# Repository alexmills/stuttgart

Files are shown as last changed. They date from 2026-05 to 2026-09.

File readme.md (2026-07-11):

# Project Stuttgart

*Last Updated: 11th July 2026*

> Named after the founding location of Bosch in 1886, where a team in 1983 started development of the Connected Area Network.

The goal for this research project is to explore the benefits of having a clearer look at the CAN bus during vehicle diagnostics, instead of relying solely on multimeter or oscilloscope measurements.

## Overview

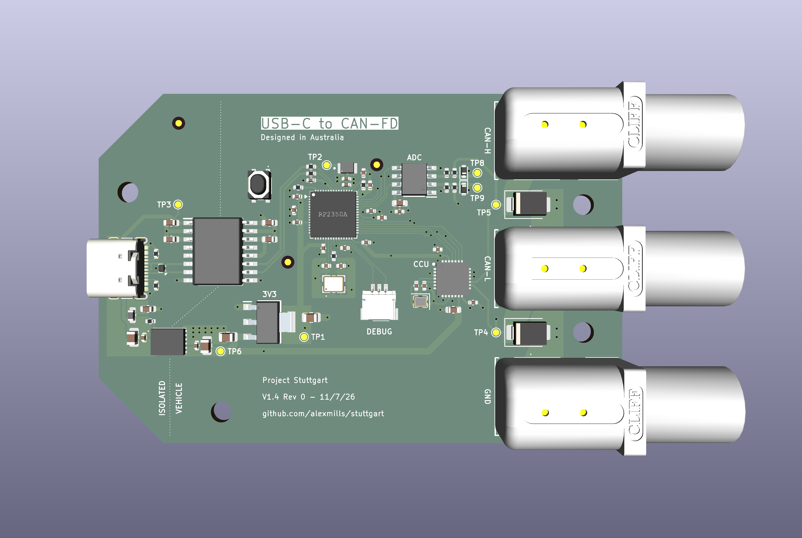
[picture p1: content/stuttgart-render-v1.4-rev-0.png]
Rev-0 3D Render


The tool connects to the CAN bus in a **read only** capacity, receiving messages and monitoring bus health while simultaneously measuring the voltage on the High and Low signal lines to identify physical layer faults. The CAN controller's transmit line is still connected for some future experiments with J1939.

A small web app connects to the tool using WebSerial (in Chrome/Edge) to control and monitor its data output in real time. 

*The design and component selection **will not** take production into consideration, this is purely a research project. I get easily sidetracked worrying about how to make n-amount instead of just making one first...*
## Isolation & Safety

The microcontroller and USB are completely isolated from the components connected to the vehicle electronics through the CAN bus, protecting the laptop and user from any potential voltage differences between chassis ground and mains earth. This isolation also eliminates ground loops, improves signal integrity, and provides a clean ground reference for the vehicle measurements.

## Target Vehicle / Networks

Primary targets are heavy duty vehicles which use a combination of J1939 and J2284 networks. The initial goal of the tool is not to decode these messages but to verify the bus is healthy and that frames are being transmitted without errors or corruption.

Both standards build on ISO 11898 *Road Vehicles - Controller Area Network (CAN),* with their own additions and modifications.

**J1939** spans both **physical** and **application** layers, defining its own physical layer specifications as well as how the messages are structured and what they mean. Unlike J2284, the use of CAN 2.0B 29-bit extended identifiers is mandated.

**J2284** defines the **physical** layer and portions of the **data link** layer, with OBD-II, UDS and proprietary **application** layers running on top. Both standards reference ISO 11898-2 for the high speed CAN physical layer, meaning the bus voltage levels are identical and the same transceiver hardware can be used across all target networks.

## Status

The current state of the project as follows:

- [x] Project Scope
- [x] Architecture & Protocol Design
- [x] Component Selection
- [x] Schematic Design
- [x] PCB Design
- [ ] Enclosure Design (Active)
- [ ] Firmware Implementation (Active)
- [ ] App Implementation (Active)
- [ ] Testing

## Updates 

### 11th July 2026
Order with JLC has been placed! Got stung with extended library part swaps so will need to revise that in the future because it was quite expensive.

## Main Components

| Component | Part No | JLC No | Status | Models |
| --- | --- | --- | --- | --- |
| MCU | Raspberry Pi RP2354A | C41378174 | ✅ | 📦 |
| CAN FD Controller | Microchip MCP251863 | C20295647 | ✅ | ✅ |
| Voltage ADC | MCP3202-CI/SN | C56997 | ✅ | ✅ |
| Isolated DC-DC | TI UCC33420 | C46461551 | ✅ | ✅ |
| Isolated USB | TI ISOUSB111DWR | C5216549  | ✅ | ✅ |
| 3.3V LDO | OnSemi NCV1117ST33T3G | C114733 | ✅ | ✅ |
| MCP2518FD Crystal | Murata XRCGE20M000F3A1AR0 | C6758395  | ✅ | 📦 |
| 12MHz Crystal | Abracon ABM8-272-T3 | C20625731 | ✅ | ✅ |
| SMPS Inductor | Abracon AOTA-B201610S3R3-101T | C42411119 | ✅ | ✅ |
| Transceiver TVS Diodes | Littelfuse SMBJ5.0A | C83333 | ✅ | 📦 |
| ADC Zener Diodes | Onsemi SZMM5Z3V3T1G | C464127 | ✅ | 📦 |
| BOOTSEL Button | Wurth 434133025816 | C5504987  | ✅ | ✅ |
| USB-C Connector | GCT USB4105-GF-060 | C3025063  | ✅ | 📦 |
| SWD Header | JST SM03B-SRSS-TB | C160403 | ✅ | ✅ |
| CANH Socket | Cliff FCR7350Y (Blue) | Digikey | ✅ | ✅ |
| CANL Socket | Cliff FCR7350G (Green) | Digikey | ✅ | ✅ |
| GND Socket | Cliff FCR7350B (Black) | Digikey | ✅ | ✅ |

## System Architecture

Below is the high level architecture of the system, including the USB/Vehicle isolation and main active components.

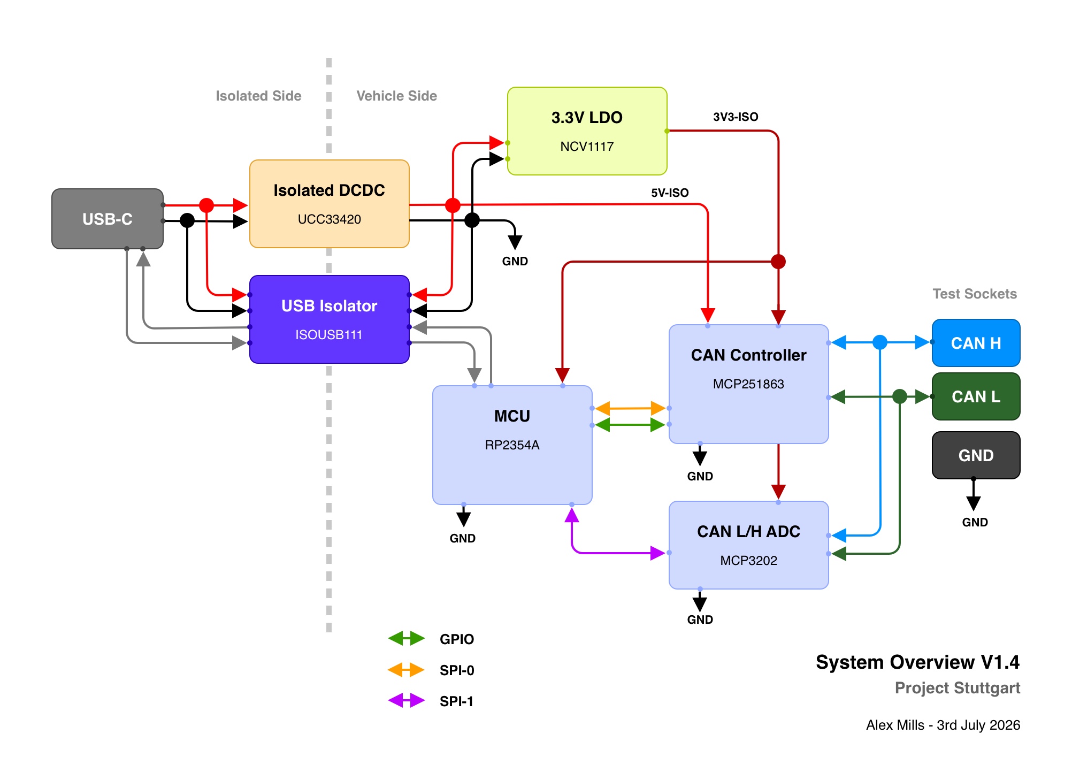
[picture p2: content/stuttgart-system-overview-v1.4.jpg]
System Overview


### Vehicle / USB Isolation

The VBUS from the USB-C connector is isolated using a Texas Instruments UCC33420 DC-DC Converter, providing 1.5W / 300mA to the 5V Rail.

The USB data is isolated using a Texas Instruments ISOUSB111 USB Isolator, which sits between the USB-C Connector and RP2354. Combining this IC with the DC-DC converter means the main components on the PCB sit on the "vehicle side", completely isolated from the USB port and connected computer.

### Vehicle Interface

The CAN communication to the vehicle is achieved using a Microchip MCP251863, integrating the MCP2518-FD Controller and ATA6563 Transceiver into a single package ([Datasheet]([https://ww1.microchip.com/downloads/aemDocuments/documents/OTH/ProductDocuments/DataSheets/External-CAN-FD-Controller-with-SPI-Interface-DS20006027B.pdf](https://ww1.microchip.com/downloads/aemDocuments/documents/APID/ProductDocuments/DataSheets/MCP251863-External-CAN-FD-Controller-with-Integrated-Transceiver-DS200066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))). The CAN Signals and vehicle reference ground are provided through CLIFF 4mm 1kV "banana" sockets usually found on multimeters, so my normal test leads and accessories can be used.

## Power Requirements

### 3V3 Rail

| Component | Typical  | Max | Notes |
| --- | --- | --- | --- |
| RP2354 | 16mA | 20mA | USB Comms Test |
| MCP2518FD | 15mA | 20mA | 40MHz SYSCLK |
| ATA6563 | 0.25mA | 0.5mA | VIO 3V3 Logic Pin |
| MCP3202 | 0.4mA | 0.55mA | VSS = 5.0V |
| **TOTAL** | **32mA** | **41mA** | |

The RP2354 draws around 16mA with constant data being written to the USB port as per the hardware data sheet. 

### LDO Thermal

The recommended LDO for the RP2354 is the NCP1117 family of which we are using the automotive version, NCV1117

**OnSemi NCP1117**
- Output: 1.0A @ 3.3V
- Maximum Junction Temperature Range: -55c to 150c
- Junction-to-ambient thermal resistance: 160c/W (SOT-223 worst case)

At maximum load of 41mA the LDO dissipates 70mW as heat, causing a junction rise above ambient of only 11c. With a realistic max enclosure temperature of 55c, a junction temperature of 66c is well within limits.

### Isolated 5V Rail

| Condition | ATA6563 | ISOUSB111 | 5V Direct Total |
| --- | --- | --- | --- |
| Startup / No Monitor | 0mA (STBY) | ~12-15mA  | **~12-15mA** |
| Passive (recessive)  | ~2-5mA | ~12-15mA  | **~14-20mA** |
| TX Burst (max dom) | 70mA | ~15mA | **~85mA** |
| **CANL/H Short** | **85mA** | **~15mA** | **~100mA** |

### Total 5V DC-DC Load

3V3 rail load reflected through the LDO at ~1:1

| Condition | 3V3 LDO | 5V Direct  | DC-DC Total | Power @ 5V |
| --- | --- | --- | --- | --- |
| Startup / No Monitor  | ~32mA | ~12mA | ~44mA | ~220mW |
| Passive Monitor (max) | ~41mA | ~17mA | ~58mA | ~290mW |
| TX Burst (max dom) | ~41mA | ~85mA | ~126mA | ~630mW |
| **Short Fault (max)** | **~32mA** | **~100mA** | **~141mA**  | **~705mW** |

### DC-DC Converter Thermal

**TI UCC33420**
- 1.5W / 300mA @ 5.0V
- Recommended Junction Temperature Range: -40 to 125c 
- Junction-to-ambient thermal resistance: 59.7c/W
- Dissipation at full load: 1050mW
- Efficiency: ~59%

At the worst case scenario, we draw 141mA or 705mW from the converter which at roughly 59% efficiency requires an input load of 1195mW or 240mA, of which 490mW is dissipated as heat equalling a rise of 29c above ambient. With the realistic max enclosure temperature of 55c, the junction temperature of 84c is well within limits.

For 99% of the time the load is much smaller at around 290mW, requiring 492mW of which 202mW is lost as heat, causing a junction rise above ambient of only 12c. 

### USB Requirements

| Condition | DC-DC Load | ISOUSB111 | VBUS Total |
| --- | --- | --- | --- |
| Startup / No Monitor  | 74mA / 372mW | ~12-15mA  | ~89mA |
| Passive Monitor (max) | 98mA / 492mW | ~12-15mA  | ~113mA |
| TX Burst (max dom) | 213mA / 1068mW | 15mA | ~228mA |
| Short Fault (max) | 240mA / 1195W  | 15mA | ~256mA |

With the transceiver in standby mode until needed, our system power requirements at boot are under the 100mA USB initial limit, which can be upped to 400-500mA with negotiations by the RP2354.

## Bus ADC Measurements

The voltage divider for each bus is `R1 = 10kΩ` and `R2 = 47kΩ` so the ratio is calculated as:

```
Vout = Vin x (R2 / (R1 + R2))
Vout = Vin x (47,000 / (10,000 + 47,000))
Vout = Vin x (47,000 / 57,000)
Vout = Vin x 0.8246
```

Below are the estimated values for the ADC measurements at various bus voltages using the above divider with a protection zener diode, clamping at ~3.3V, keeping the ADC within safe limits (3.6V Max). 

| Bus Voltage | ADC Voltage | RAW ADC Value | Notes |
| --- | --- | --- | --- |
| 0 | 0 | 0 | Bus Dead / Off |
| 1.5 | 1.237 | 1535 | CAN L Dominant |
| 2.5 | 2.062 | 2559 | Recessive Idle |
| 3.5 | 2.886 | 3583 | CAN H Dominant |
| **3.9** | **3.223** | **4000** | **Clean bus fault threshold** |
| 4.0 | 3.300 | 4095 | Zener Activates |
| Over 4.0 | 3.300 | 4095 | Clamped - Fault Condition |

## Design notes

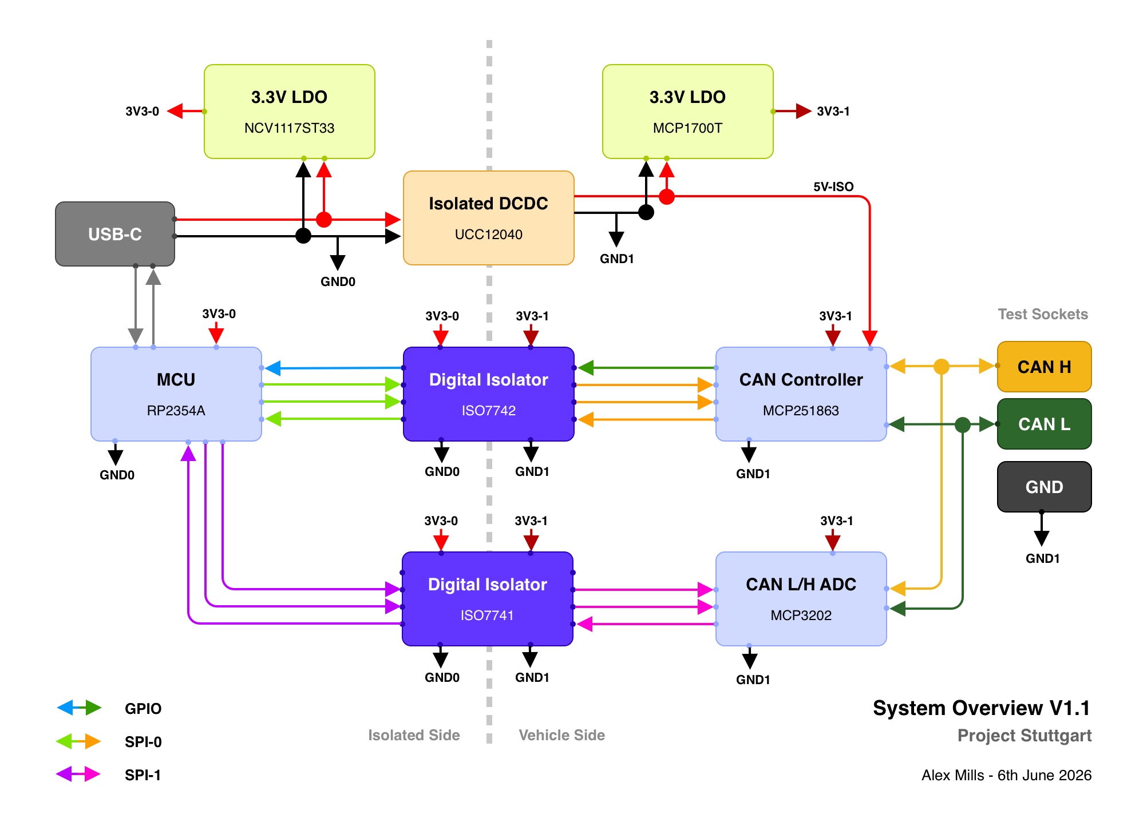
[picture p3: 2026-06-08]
content/stuttgart-system-overview-v1.1.jpg

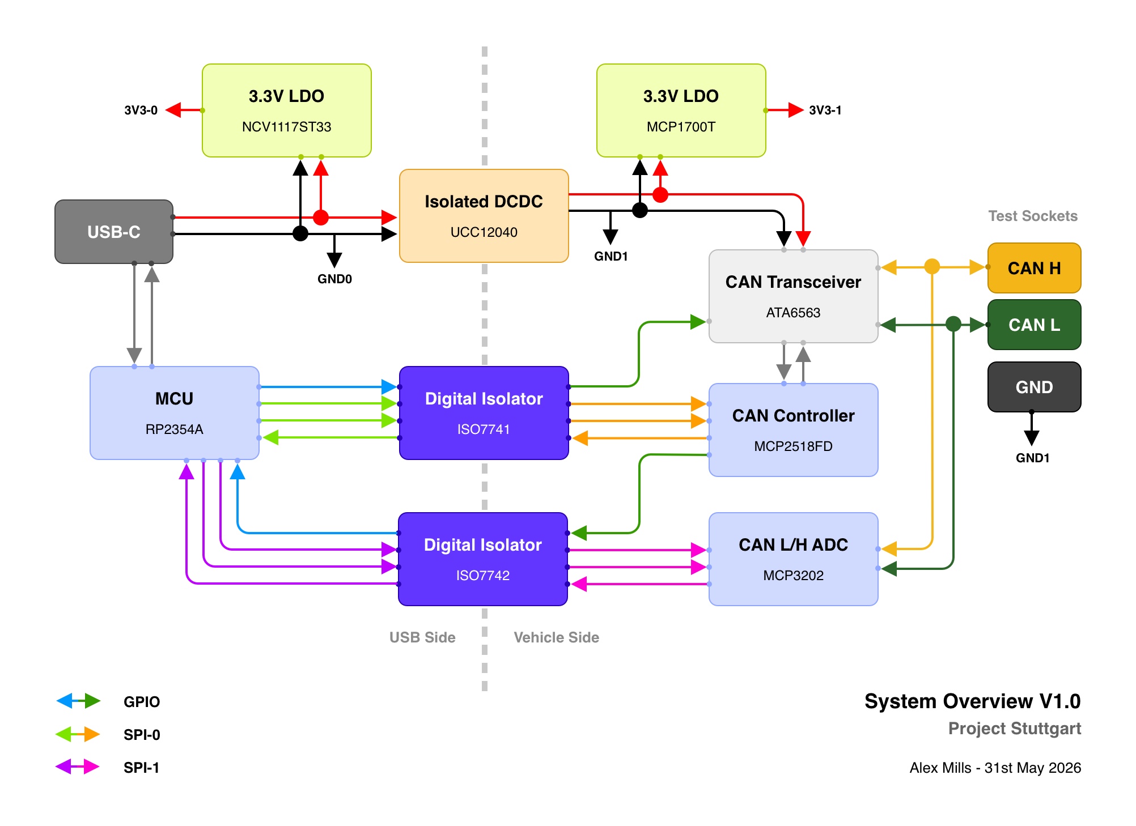
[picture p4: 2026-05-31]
content/stuttgart-system-overview-v1.jpg

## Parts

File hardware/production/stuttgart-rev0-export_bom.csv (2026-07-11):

Designator | Footprint | Quantity | Value | LCSC Part #
C1, C10, C2, C29, C3, C30, C31, C4, C5, C6, C7, C8 | 0402 | 12 | 100n
C11, C12, C18 | 0805 | 3 | 10u
C13, C14 | 0402 | 2 | 15p
C15, C16, C17, C9 | 0402 | 4 | 4.7u
C19, C20 | 0402 | 2 | 15n
C21 | 0805 | 1 | 22u
C28 | 0603 | 1 | 10u
C32, C35 | 0603 | 2 | 100n
C33, C34 | 0402 | 2 | 6p
C36, C37 | 0603 | 2 | 1u
C38, C39 | 0603 | 2 | 0.1u
D1, D2 | D_SOD-523 | 2 | MM5Zxx
D3, D4 | D_SMB | 2 | SM6T6V8A
FB1 | 0603 | 1 | FerriteBead
IC1 | SOT230P700X180-4N | 1 | NCV1117ST33T3G
IC2 | UCC33020QRAQRQ1 | 1 | UCC33420QRAQRQ1
IC3 | SOIC127P1030X265-16N | 1 | ISOUSB111DWR
IC6 | SOIC127P600X175-8N | 1 | MCP3202-CI_SN
IC7 | QFN50P500X500X90-29N-D | 1 | MCP251863T-E_9PX
J1 | USB_C_Receptacle_GCT_USB4105-xx-A_16P_TopMnt_Horizontal | 1 | USB_C_Receptacle_USB2.0_16P
J5 | SM03BSRSSTBLFSN | 1 | SM03B-SRSS-TB_LF__SN_
L1 | AOTAB201610S3R3101T | 1 | AOTA-B201610S3R3-101-T
R1, R2 | 0402 | 2 | 27
R10, R8 | 0402 | 2 | 10k
R11, R9 | 0402 | 2 | 47k
R12 | 0402 | 1 | 18k
R3, R6 | 0402 | 2 | 1k
R4, R5 | 0402 | 2 | 5.1k
R7 | 0402 | 1 | 33
S1 | 434133025816 | 1 | 434133025816
U1 | QFN-60-1EP_7x7mm_P0.4mm_EP3.4x3.4mm | 1 | RP2354A
U2 | Texas_DRT-3 | 1 | TPD2EUSB30
Y1 | ABM8272T3 | 1 | ABM8-272-T3
Y2 | Crystal_SMD_2016-4Pin_2.0x1.6mm | 1 | Crystal_GND24

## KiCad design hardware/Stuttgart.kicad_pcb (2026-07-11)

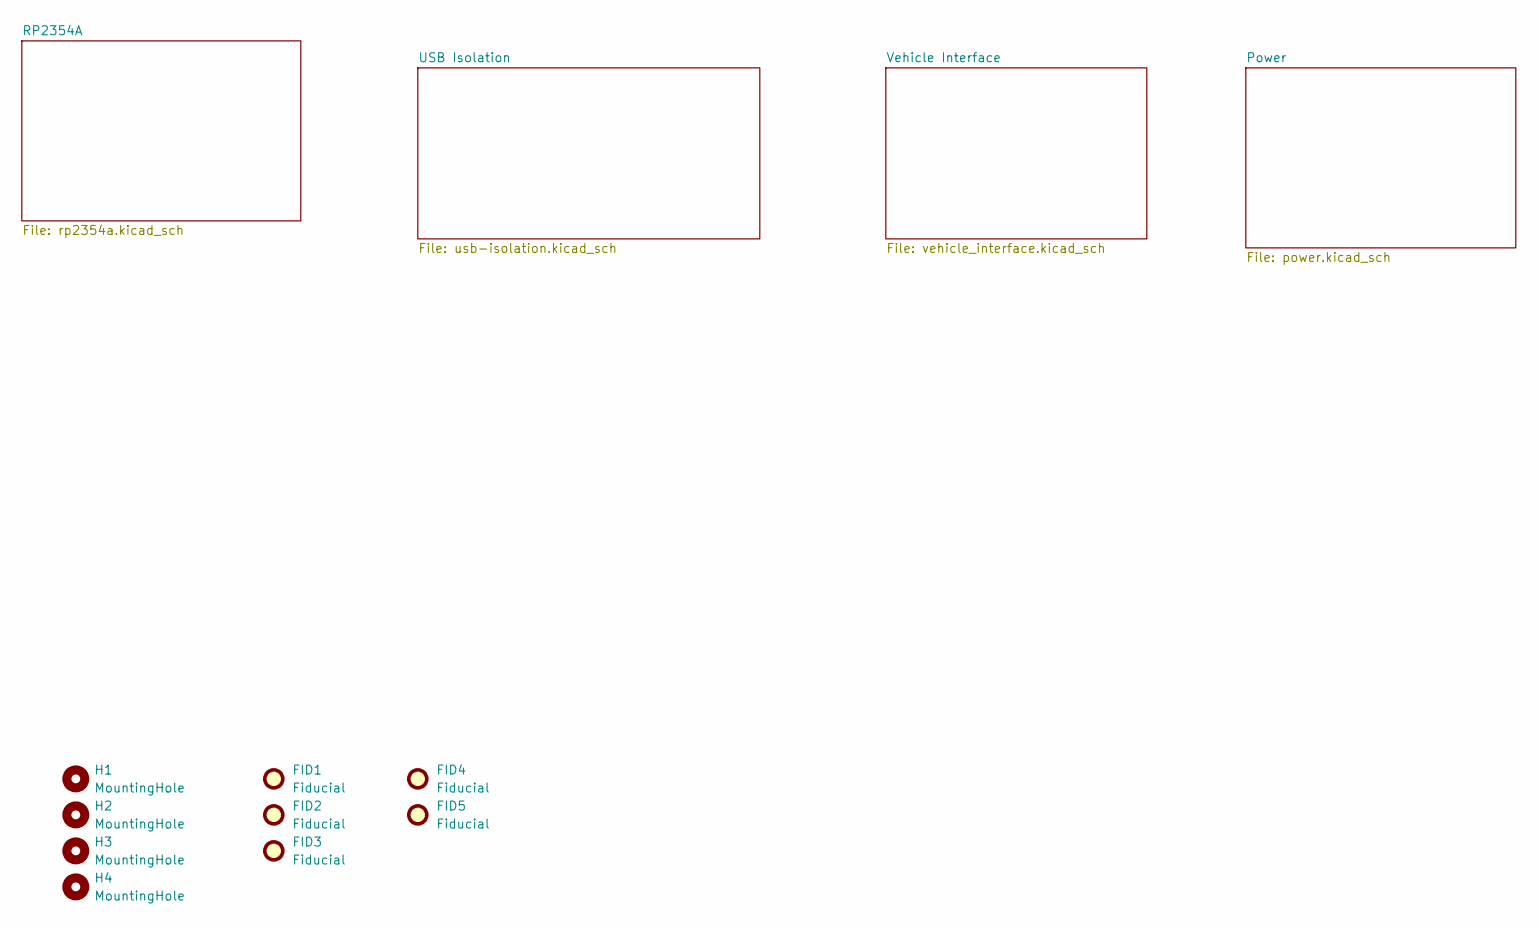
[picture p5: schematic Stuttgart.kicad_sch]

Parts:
FID1, FID2, FID3, FID4, FID5: Fiducial; Fiducial_1mm_Mask2mm
H1, H2, H3, H4: MountingHole; MountingHole_3.2mm_M3

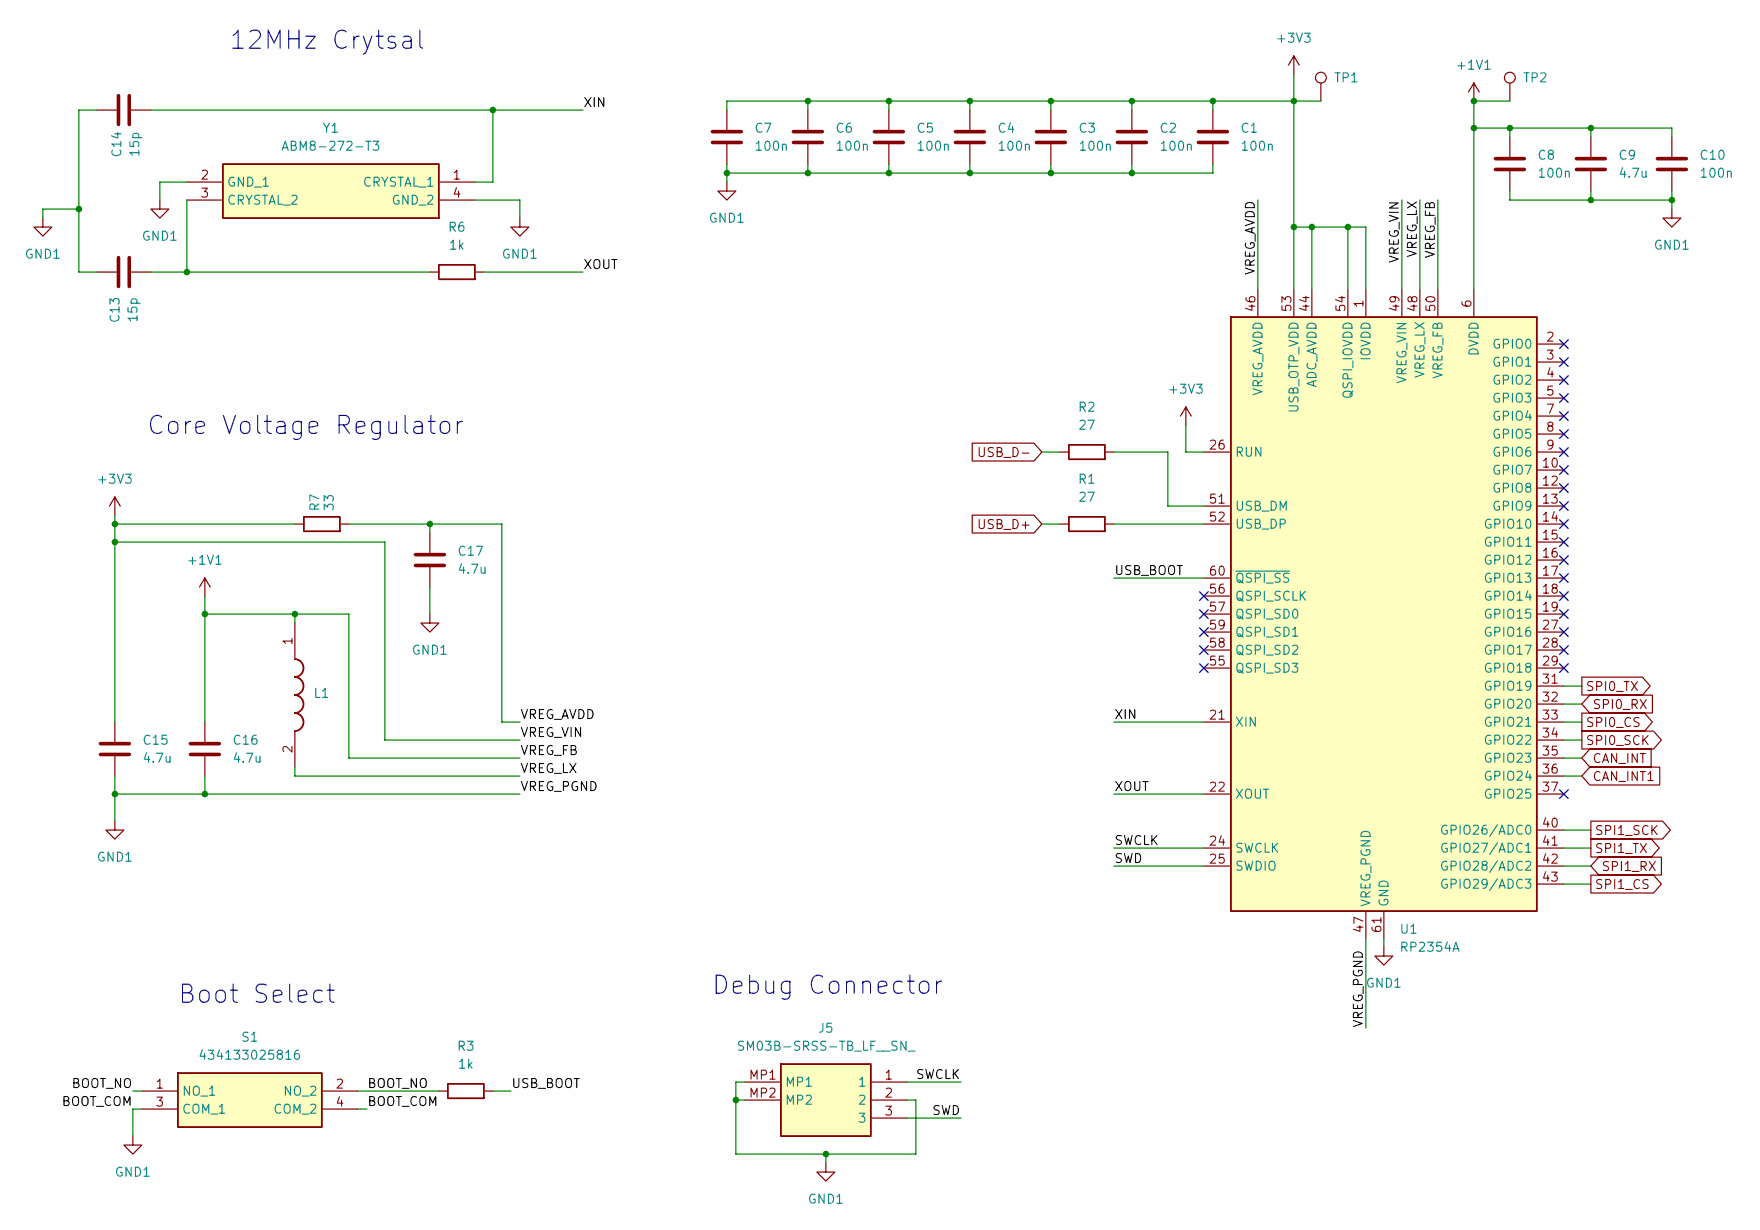
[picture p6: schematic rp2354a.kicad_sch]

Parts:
C1, C2, C3, C4, C5, C6, C7, C8, C10: 100n; C_0402_1005Metric
C9, C17: 4.7u; C_0402_1005Metric
C13, C14: 15p; C_0402_1005Metric
C15, C16: 4.7u; C_0402_1005Metric_small_pads
J5: SM03B-SRSS-TB_LF__SN_; SM03BSRSSTBLFSN; Manufacturer_Part_Number SM03B-SRSS-TB(LF)(SN); JLC Part Number C160403
L1: AOTA-B201610S3R3-101-T; AOTAB201610S3R3101T; Mouser Part Number 815-AB201610S3R3101T
R1, R2: 27; R_0402_1005Metric
R3, R6: 1k; R_0402_1005Metric
R7: 33; R_0402_1005Metric
S1: 434133025816; Manufacturer_Part_Number 434133025816; JLC Part Number C5504987
TP1, TP2: TestPoint; TestPoint_Pad_D1.0mm
U1: RP2354A; QFN-60-1EP_7x7mm_P0.4mm_EP3.4x3.4mm; JLC Part Number C41378174
Y1: ABM8-272-T3; ABM8272T3; Mouser Part Number 815-ABM8-272-T3

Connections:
+1V1: C8.1, C9.1, C10.1, C16.1, L1.1, TP2.1 (1_1), U1.6 (DVDD), U1.23 (DVDD), U1.39 (DVDD), U1.50 (VREG_FB)
+3V3: C1.1, C2.1, C3.1, C4.1, C5.1, C6.1, C7.1, C15.1, R7.1, TP1.1 (1_1), U1.1 (IOVDD), U1.11 (IOVDD), U1.20 (IOVDD), U1.26 (RUN), U1.30 (IOVDD), U1.38 (IOVDD), U1.44 (ADC_AVDD), U1.45 (IOVDD), U1.49 (VREG_VIN), U1.53 (USB_OTP_VDD), U1.54 (QSPI_IOVDD); also elsewhere on the board
/RP2354A/BOOT_NO: R3.1, S1.1 (NO_1), S1.2 (NO_2)
/RP2354A/SWCLK: J5.1, U1.24 (SWCLK)
/RP2354A/SWD: J5.3, U1.25 (SWDIO)
/RP2354A/USB_BOOT: R3.2, U1.60 (~QSPI_SS)
/RP2354A/VREG_AVDD: C17.1, R7.2, U1.46 (VREG_AVDD)
/RP2354A/VREG_LX: L1.2, U1.48 (VREG_LX)
/RP2354A/XIN: C14.2, U1.21 (XIN), Y1.1 (CRYSTAL_1)
/RP2354A/XOUT: R6.2, U1.22 (XOUT)
CAN_INT: U1.35 (GPIO23); also elsewhere on the board
CAN_INT1: U1.36 (GPIO24); also elsewhere on the board
GND1: C1.2, C2.2, C3.2, C4.2, C5.2, C6.2, C7.2, C8.2, C9.2, C10.2, C13.2, C14.1, C15.2, C16.2, C17.2, J5.2, J5.MP1, J5.MP2, S1.3 (COM_1), S1.4 (COM_2), U1.47 (VREG_PGND), U1.61 (GND), Y1.2 (GND_1), Y1.4 (GND_2); also elsewhere on the board
unnamed: R2.2, U1.51 (USB_DM)
unnamed: R1.2, U1.52 (USB_DP)
unnamed: C13.1, R6.1, Y1.3 (CRYSTAL_2)
SPI0_CS: U1.33 (GPIO21); also elsewhere on the board
SPI0_RX: U1.32 (GPIO20); also elsewhere on the board
SPI0_SCK: U1.34 (GPIO22); also elsewhere on the board
SPI0_TX: U1.31 (GPIO19); also elsewhere on the board
SPI1_CS: U1.43 (GPIO29/ADC3); also elsewhere on the board
SPI1_RX: U1.42 (GPIO28/ADC2); also elsewhere on the board
SPI1_SCK: U1.40 (GPIO26/ADC0); also elsewhere on the board
SPI1_TX: U1.41 (GPIO27/ADC1); also elsewhere on the board
USB_D+: R1.1; also elsewhere on the board
USB_D-: R2.1; also elsewhere on the board

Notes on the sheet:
Debug Connector
Boot Select
12MHz Crytsal
Core Voltage Regulator

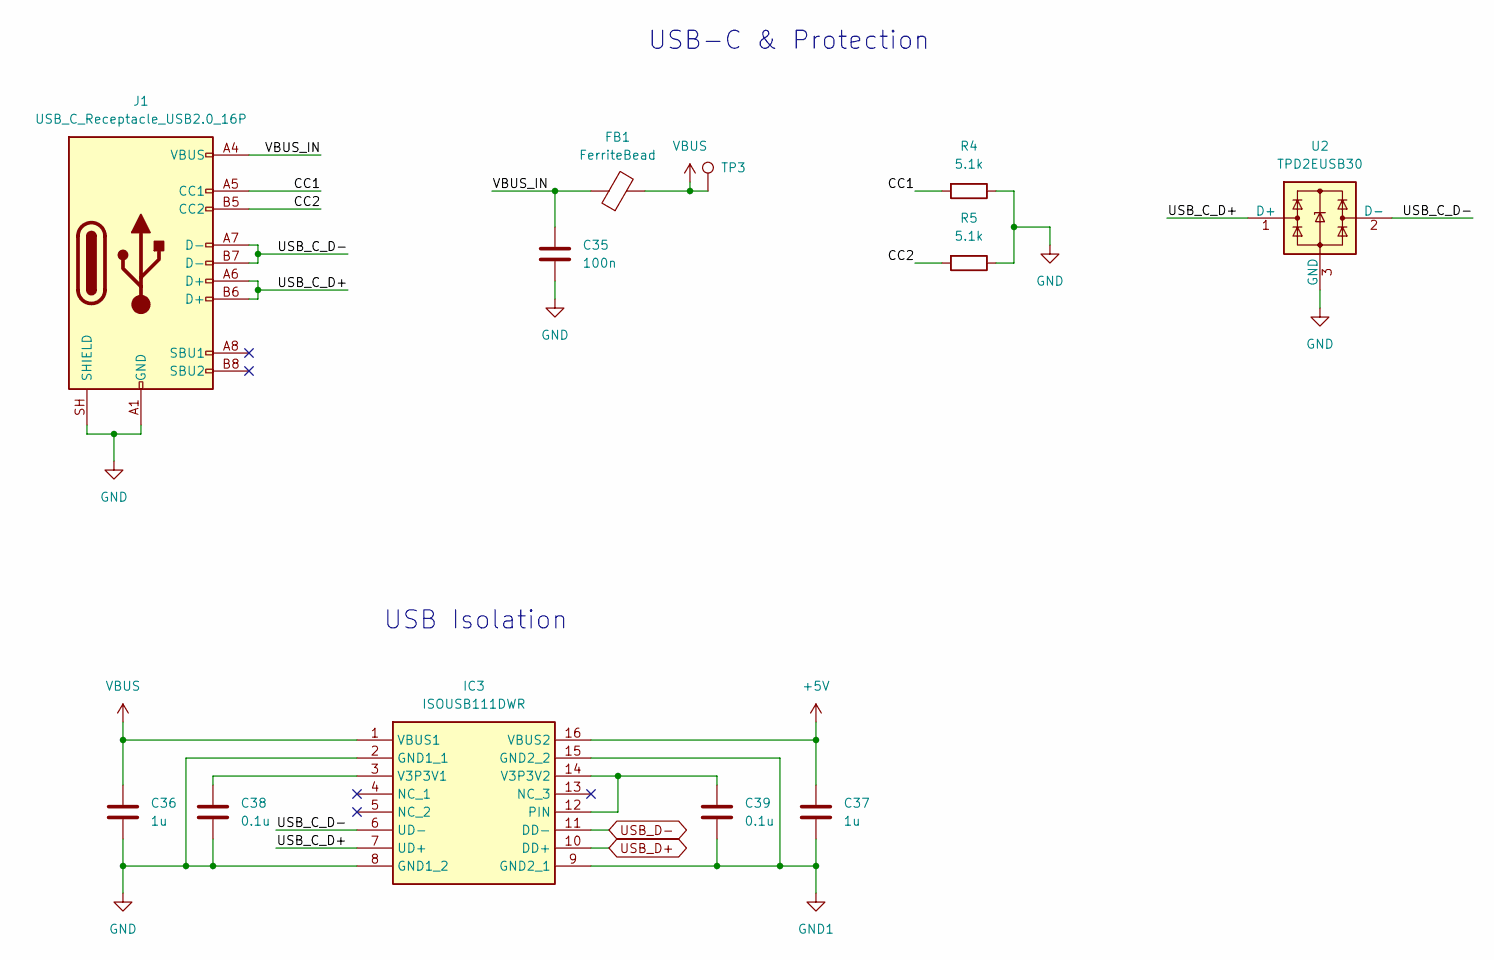
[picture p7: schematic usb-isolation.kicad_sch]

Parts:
C35: 100n; C_0603_1608Metric
C36, C37: 1u; C_0603_1608Metric
C38, C39: 0.1u; C_0603_1608Metric
FB1: FerriteBead; L_0603_1608Metric; JLC Part Number C82155
IC3: ISOUSB111DWR; SOIC127P1030X265-16N; Mouser Part Number 595-ISOUSB111DWR
J1: USB_C_Receptacle_USB2.0_16P; USB_C_Receptacle_GCT_USB4105-xx-A_16P_TopMnt_Horizontal; JLC Part Number C3025063
R4, R5: 5.1k; R_0402_1005Metric
TP3: TestPoint; TestPoint_Pad_D1.0mm
U2: TPD2EUSB30; Texas_DRT-3; JLC Part Number C97502

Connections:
+5V: C37.1, IC3.16 (VBUS2); also elsewhere on the board
/USB Isolation/CC1: J1.A5 (CC1), R4.2
/USB Isolation/CC2: J1.B5 (CC2), R5.2
/USB Isolation/USB_C_D+: IC3.7 (UD+), J1.A6 (D+), J1.B6 (D+), U2.1 (D+)
/USB Isolation/USB_C_D-: IC3.6 (UD-), J1.A7 (D-), J1.B7 (D-), U2.2 (D-)
/USB Isolation/VBUS_IN: C35.1, FB1.1, J1.A4 (VBUS), J1.A9 (VBUS), J1.B4 (VBUS), J1.B9 (VBUS)
GND: C35.2, C36.2, C38.2, IC3.2 (GND1_1), IC3.8 (GND1_2), J1.A1 (GND), J1.A12 (GND), J1.B1 (GND), J1.B12 (GND), J1.SH (SHIELD), R4.1, R5.1, U2.3 (GND); also elsewhere on the board
GND1: C37.2, C39.2, IC3.9 (GND2_1), IC3.15 (GND2_2); also elsewhere on the board
unnamed: C39.1, IC3.12 (PIN), IC3.14 (V3P3V2)
unnamed: C38.1, IC3.3 (V3P3V1)
USB_D+: IC3.10 (DD+); also elsewhere on the board
USB_D-: IC3.11 (DD-); also elsewhere on the board
VBUS: C36.1, FB1.2, IC3.1 (VBUS1), TP3.1 (1_1); also elsewhere on the board

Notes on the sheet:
USB Isolation
USB-C & Protection

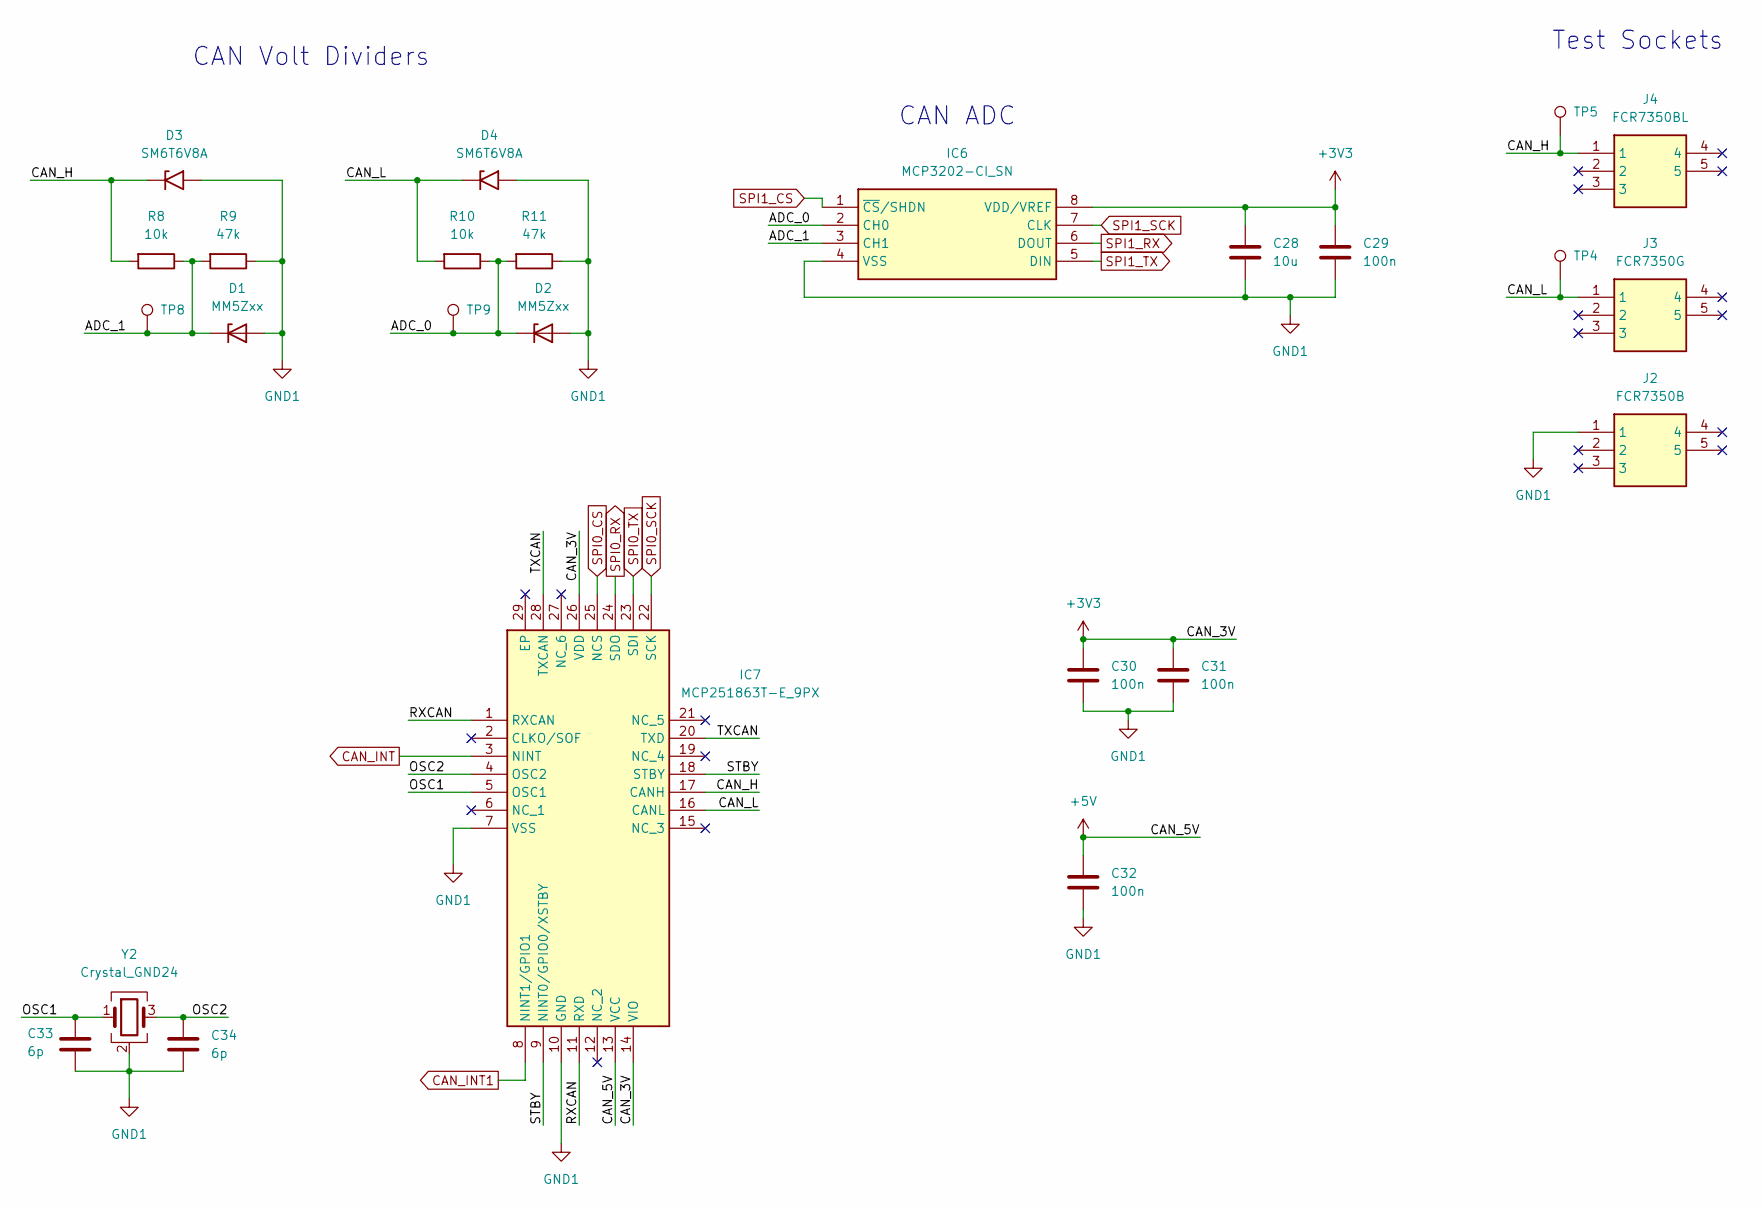
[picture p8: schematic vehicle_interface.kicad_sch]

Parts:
C28: 10u; C_0603_1608Metric
C29, C30, C31: 100n; C_0402_1005Metric
C32: 100n; C_0603_1608Metric
C33, C34: 6p; C_0402_1005Metric
D1, D2: MM5Zxx; D_SOD-523; JLC Part Number C464127
D3, D4: SM6T6V8A; D_SMB; JLC Part Number C83333
IC6: MCP3202-CI_SN; SOIC127P600X175-8N; Mouser Part Number 579-MCP3202-CI/SN
IC7: MCP251863T-E_9PX; QFN50P500X500X90-29N-D; Mouser Part Number 579-MCP251863T-E/9PX
J2: FCR7350B; FCR7350G; Manufacturer_Part_Number FCR7350G
J3: FCR7350G; Manufacturer_Part_Number FCR7350G
J4: FCR7350BL; FCR7350G; Manufacturer_Part_Number FCR7350G
R8, R10: 10k; R_0402_1005Metric
R9, R11: 47k; R_0402_1005Metric
TP4, TP5, TP8, TP9: TestPoint; TestPoint_Pad_D1.0mm
Y2: Crystal_GND24; Crystal_SMD_2016-4Pin_2.0x1.6mm; JLC Part Number C6758395

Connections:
+3V3: C28.1, C29.1, C30.1, C31.1, IC6.8 (VDD/VREF), IC7.14 (VIO), IC7.26 (VDD); also elsewhere on the board
+5V: C32.1, IC7.13 (VCC); also elsewhere on the board
/Vehicle Interface/ADC_0: D2.1 (K), IC6.2 (CH0), R10.1, R11.2, TP9.1 (1_1)
/Vehicle Interface/ADC_1: D1.1 (K), IC6.3 (CH1), R8.1, R9.2, TP8.1 (1_1)
/Vehicle Interface/CAN_H: D3.1 (A1), IC7.17 (CANH), J4.1 (1_1), R8.2, TP5.1 (1_1)
/Vehicle Interface/CAN_L: D4.1 (A1), IC7.16 (CANL), J3.1 (1_1), R10.2, TP4.1 (1_1)
/Vehicle Interface/OSC1: C33.1, IC7.5 (OSC1), Y2.1
/Vehicle Interface/OSC2: C34.1, IC7.4 (OSC2), Y2.3
/Vehicle Interface/RXCAN: IC7.1 (RXCAN), IC7.11 (RXD)
/Vehicle Interface/STBY: IC7.9 (NINT0/GPIO0/XSTBY), IC7.18 (STBY)
/Vehicle Interface/TXCAN: IC7.20 (TXD), IC7.28 (TXCAN)
CAN_INT: IC7.3 (NINT); also elsewhere on the board
CAN_INT1: IC7.8 (NINT1/GPIO1); also elsewhere on the board
GND1: C28.2, C29.2, C30.2, C31.2, C32.2, C33.2, C34.2, D1.2 (A), D2.2 (A), D3.2 (A2), D4.2 (A2), IC6.4 (VSS), IC7.7 (VSS), IC7.10 (GND), J2.1 (1_1), R9.1, R11.1, Y2.2 (G), Y2.4 (G); also elsewhere on the board
SPI0_CS: IC7.25 (NCS); also elsewhere on the board
SPI0_RX: IC7.24 (SDO); also elsewhere on the board
SPI0_SCK: IC7.22 (SCK); also elsewhere on the board
SPI0_TX: IC7.23 (SDI); also elsewhere on the board
SPI1_CS: IC6.1 (~CS/SHDN); also elsewhere on the board
SPI1_RX: IC6.6 (DOUT); also elsewhere on the board
SPI1_SCK: IC6.7 (CLK); also elsewhere on the board
SPI1_TX: IC6.5 (DIN); also elsewhere on the board

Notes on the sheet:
CAN ADC
Test Sockets
CAN Volt Dividers

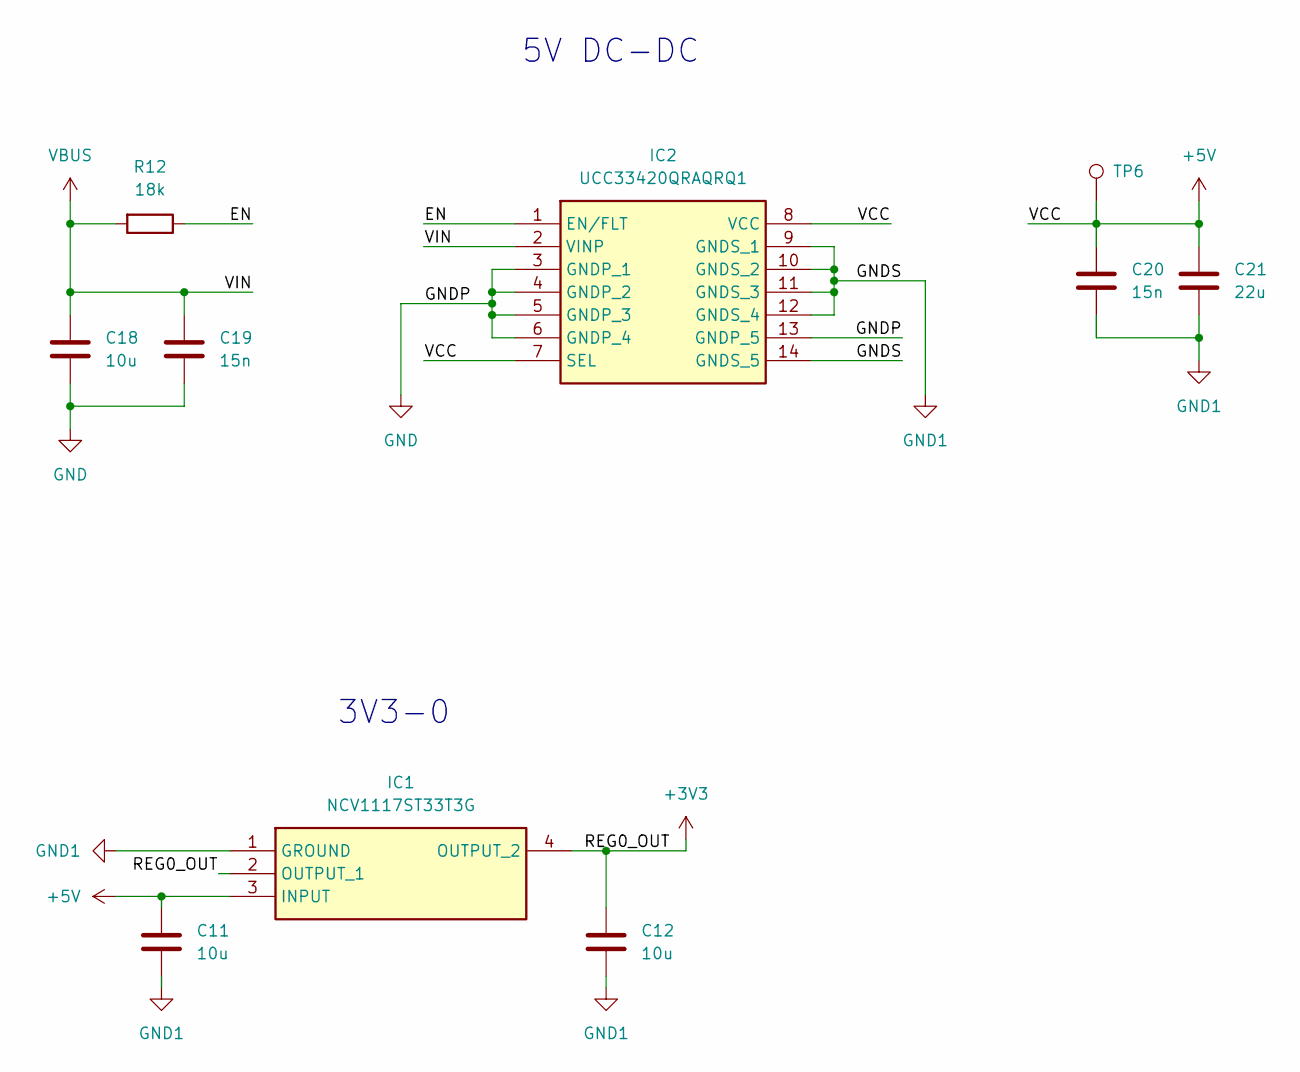
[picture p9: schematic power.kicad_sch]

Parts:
C11, C12, C18: 10u; C_0805_2012Metric
C19, C20: 15n; C_0402_1005Metric
C21: 22u; C_0805_2012Metric
IC1: NCV1117ST33T3G; SOT230P700X180-4N; Mouser Part Number 863-NCV1117ST33T3G
IC2: UCC33420QRAQRQ1; UCC33020QRAQRQ1; Mouser Part Number 595-UCC33420QRAQRQ1
R12: 18k; R_0402_1005Metric
TP6: TestPoint; TestPoint_Pad_D1.0mm

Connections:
+3V3: C12.1, IC1.2 (OUTPUT_1), IC1.4 (OUTPUT_2); also elsewhere on the board
+5V: C11.1, C20.1, C21.1, IC1.3 (INPUT), IC2.7 (SEL), IC2.8 (VCC), TP6.1 (1_1); also elsewhere on the board
/Power/EN: IC2.1 (EN/FLT), R12.1
GND: C18.2, C19.2, IC2.3 (GNDP_1), IC2.4 (GNDP_2), IC2.5 (GNDP_3), IC2.6 (GNDP_4), IC2.13 (GNDP_5); also elsewhere on the board
GND1: C11.2, C12.2, C20.2, C21.2, IC1.1 (GROUND), IC2.9 (GNDS_1), IC2.10 (GNDS_2), IC2.11 (GNDS_3), IC2.12 (GNDS_4), IC2.14 (GNDS_5); also elsewhere on the board
VBUS: C18.1, C19.1, IC2.2 (VINP), R12.2; also elsewhere on the board

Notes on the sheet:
3V3-0
5V DC-DC

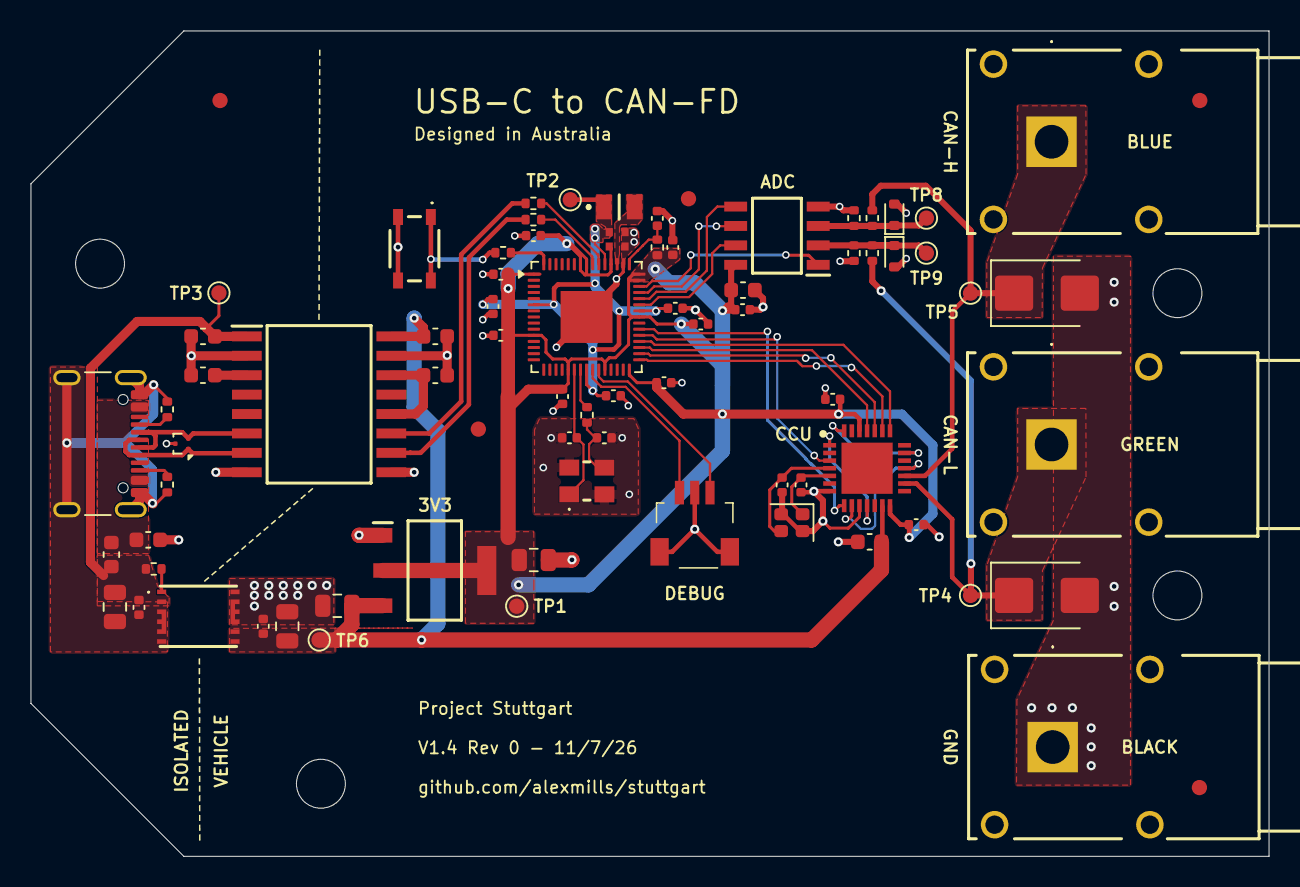
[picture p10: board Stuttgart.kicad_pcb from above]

Board: 2 copper layers, 81.0 x 54.0 mm, 83 parts (0 on the bottom side), 46 nets.

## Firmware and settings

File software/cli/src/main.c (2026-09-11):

#include <stdio.h>
#include "port.h"

#define STG_VERSION "0.1.1"

int main(int argc, char **argv) {

    // Always print version number
    printf("Stuttgart %s\n", STG_VERSION);
    
    if (argc < 2) {
        fprintf(stderr, "usage: %s <port>\n", argv[0]);
        return 1;
    }

    char err[256];
    stg_port *p = stg_port_open(argv[1], err, sizeof err);
    if (p == NULL) {
        fprintf(stderr, "%s\n", err);
        return 1;
    }

    printf("opened %s\n", argv[1]);

    uint8_t buf[256];
    for (;;) {
        
        int n = stg_port_read(p, buf, sizeof buf);
        
        if (n < 0) {
            fprintf(stderr, "read error\n");
            break;
        }

        for (int i = 0; i < n; i++) {
            printf("%02X ", buf[i]);
        }

        if (n > 0) fflush(stdout);
    }

    stg_port_close(p);
    return 0;
}

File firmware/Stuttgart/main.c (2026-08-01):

#include "pico/stdlib.h"
#include "pico/time.h"
#include "tusb.h"
#include "packet.h"

#define DEBUG_LOG_INTERVAL_MS 1000

// --- TinyUSB device callbacks ---
void tud_mount_cb(void) {}
void tud_unmount_cb(void) {}
void tud_suspend_cb(bool remote_wakeup_en) { (void)remote_wakeup_en; } 
void tud_resume_cb(void) {}


int main()
{
    
    tusb_init();

    absolute_time_t next_send = make_timeout_time_ms(DEBUG_LOG_INTERVAL_MS);
    uint32_t counter = 0;

    while(1) {
        tud_task();  // TinyUSB - Must be called contiuously

        if (time_reached(next_send)) {
            next_send = make_timeout_time_ms(DEBUG_LOG_INTERVAL_MS);

            // Only bother building/sending if a host is actually listening
            // (DTR asserted). Otherwise this would just silently accumulate in
            // TinyUSB's internal TX buffer for no reason.
            if (tud_cdc_connected()) {
                char msg[32];
                int msg_len = snprintf(msg, sizeof(msg), "heartbeat #%lu", (unsigned long)counter++);

                uint8_t frame[PKT_DEBUG_LOG_MAX_LENGTH];
                size_t frame_len = pack_debug_log(frame, time_us_64(), DEBUG_LOG_LEVEL_INFO, msg, (uint8_t)msg_len);

                // Skip rather than block if TinyUSB's TX buffer doesn't have 
                // room - avoids stalling thw whole loop (and tud_task())
                // waiting on a host that isn't draining fast enough
                if (tud_cdc_write_available() >= frame_len) {
                    tud_cdc_write(frame, frame_len);
                    tud_cdc_write_flush();
                }
            }
        }
    }
}

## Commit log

2026-04-21 Base project with Pico and CAN Controller
    [Stuttgart.kicad_pcb, Stuttgart.kicad_sch, can_interface.kicad_sch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]
2026-05-23 Revert "Base project with Pico and CAN Controller"
    This reverts commit e5296eb5b1981e33b805241d96949a49cbd533ba.
    [Stuttgart.kicad_pcb, Stuttgart.kicad_sch, can_interface.kicad_sch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]
2026-05-31 Base project with additional component symbols and footprints
    [Stuttgart.kicad_pcb, Stuttgart.kicad_sch]
2026-06-01 Initial batch of components from the minimal-bom example
    [Stuttgart.kicad_pcb, Stuttgart.kicad_sch, rp2354a.kicad_sch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]
2026-06-01 Most RP components on board. Core regulator wired up
    [Stuttgart.kicad_pcb, Stuttgart.kicad_sch, rp2354a.kicad_sch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]
2026-06-02 Wired in RP Crystal
    [Stuttgart.kicad_pcb, rp2354a.kicad_sch]
2026-06-05 Further RP development - Kicad keeps crashing
    [Stuttgart.kicad_pcb, rp2354a.kicad_sch]
2026-06-06 Core RP pad work complete
    [Stuttgart.kicad_pcb, rp2354a.kicad_sch]
2026-06-06 Boot select button added
    [Stuttgart.kicad_pcb]
2026-06-07 Added DCDC IC
    [Stuttgart.kicad_pcb, Stuttgart.kicad_sch, isolation.kicad_sch]
2026-06-08 Added 3V3-1 LDO
    [Stuttgart.kicad_pcb, isolation.kicad_sch]
2026-06-09 Further ISO bridge development
    [Stuttgart.kicad_pcb, isolation.kicad_sch]
2026-06-11 Isolation bridges complete
    [Stuttgart.kicad_pcb, isolation.kicad_sch, rp2354a.kicad_sch]
2026-06-11 CAN ADC on the board
    [Stuttgart.kicad_pcb, isolation.kicad_sch, rp2354a.kicad_sch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]
2026-06-12 Further CAN IC work before reworking SPI bridges
    [Stuttgart.kicad_pcb, vehicle_interface.kicad_sch]
2026-06-13 Left hand layout and USB power complete
    [Stuttgart.kicad_pcb]
2026-06-14 Further CAN controller development
    [Stuttgart.kicad_pcb, vehicle_interface.kicad_sch]
2026-06-17 Schematic nearly complete. Board size finalised.
    [Stuttgart.kicad_pcb, Stuttgart.kicad_sch]
2026-06-21 Completed ADC, new components and test points
    [Stuttgart.kicad_pcb, isolation.kicad_sch, rp2354a.kicad_sch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]
2026-06-23 Prep for new Isolation concept
    [Stuttgart.kicad_pcb]
2026-07-03 Added new DCDC to library
    [Stuttgart.kicad_pcb, isolation.kicad_sch]
2026-07-05 Moved GND points, revised DCDC and base USB Work
    [Stuttgart.kicad_pcb, Stuttgart.kicad_sch, power.kicad_sch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]
2026-07-05 Improved USB Protection
    [Stuttgart.kicad_pcb, usb-isolation.kicad_sch]
2026-07-05 Schematic complete and base components placed
    [Stuttgart.kicad_pcb, usb-isolation.kicad_sch]
2026-07-10 Schematic and PCB layout near final
    [Stuttgart.kicad_pcb, power.kicad_sch, rp2354a.kicad_sch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]
2026-07-11 Hardware layout complete
    [Stuttgart.kicad_pcb, usb-isolation.kicad_sch]
2026-07-11 Test Terminal Fix
    [vehicle_interface.kicad_sch]
2026-07-11 Board outline and fiducials
    [Stuttgart.kicad_pcb, Stuttgart.kicad_sch]
2026-07-11 Final visual changes
    [Stuttgart.kicad_pcb]
2026-07-11 Schematic Clean Up
    [Stuttgart.kicad_pcb, Stuttgart.kicad_sch, power.kicad_sch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]
2026-07-11 Refactor via drill sizes because I read docs wrong
    [Stuttgart.kicad_pcb]
2026-07-11 Added production files
    [Stuttgart.kicad_pcb, stuttgart-rev0-export_bom.csv, stuttgart-rev0-export_designators.csv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]
2026-07-19 Main thread and worker handling of serial port
2026-07-24 component.render() calls now in animation frames
2026-07-26 Better main thread to worker communication
2026-07-31 Base Pico project
2026-08-01 End to end DEBUG_LOG from device to DB!
2026-09-11 Added framer and project tests
